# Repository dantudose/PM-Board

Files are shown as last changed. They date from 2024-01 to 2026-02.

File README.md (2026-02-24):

# PM-Board

## Embedded development board with ATmega324P

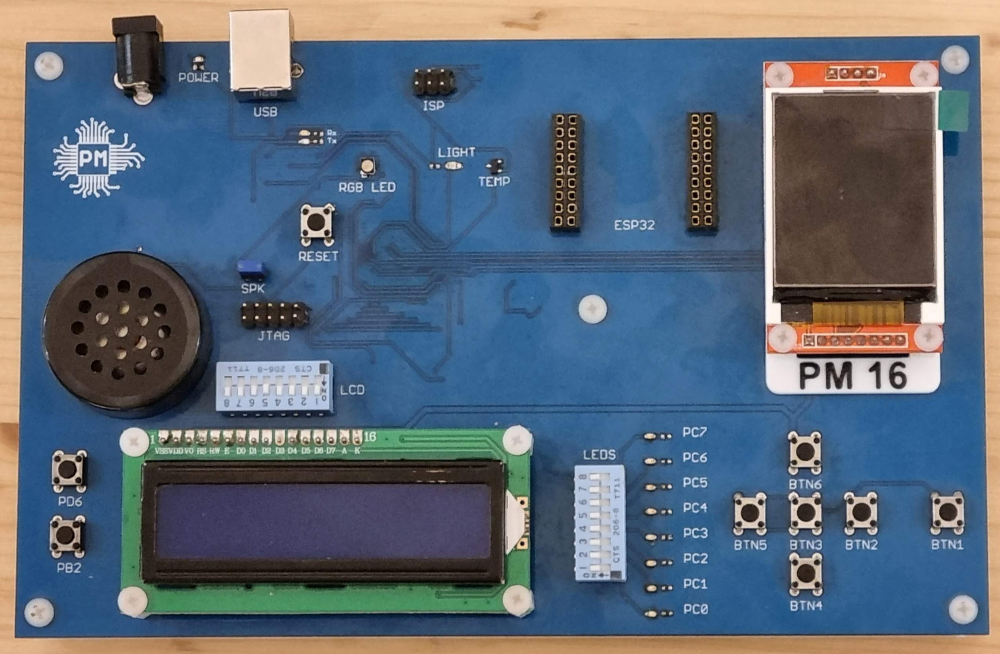
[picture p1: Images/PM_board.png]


This is a development board supporting the ATmega324P microcontroller. It is fully Arduino-compatible and it comes with the following features:
* LSM9DS0 9-axis inertial sensor (accelerometer, gyroscope and magnetometer)
* MPL3115 baro-altimeter sensor
* Ambient temperature and light sensors
* 128x160 ST7735 color LCD display with SD card reader 
* RGB LED
* 16x02 character LCD display
* GPIO LEDs and pushbuttons
* JTAG and ISP connectors
* USB programming and data interface

<div id="cover">
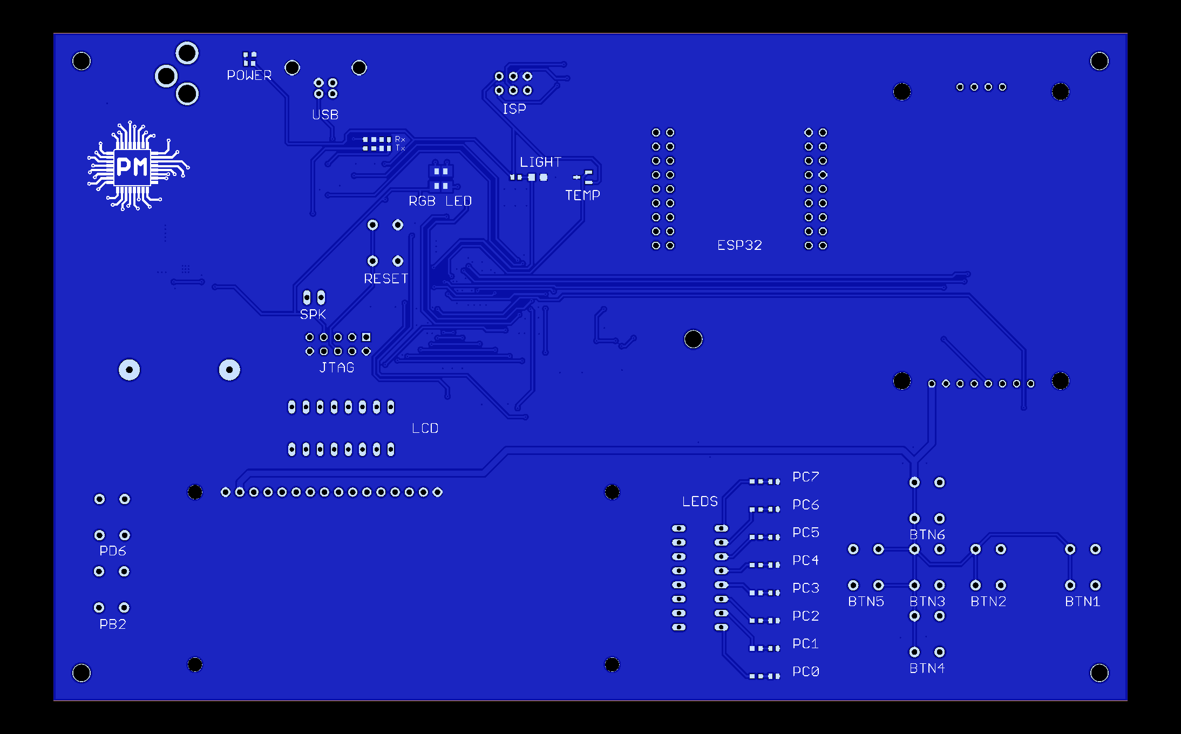
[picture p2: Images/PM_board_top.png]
  
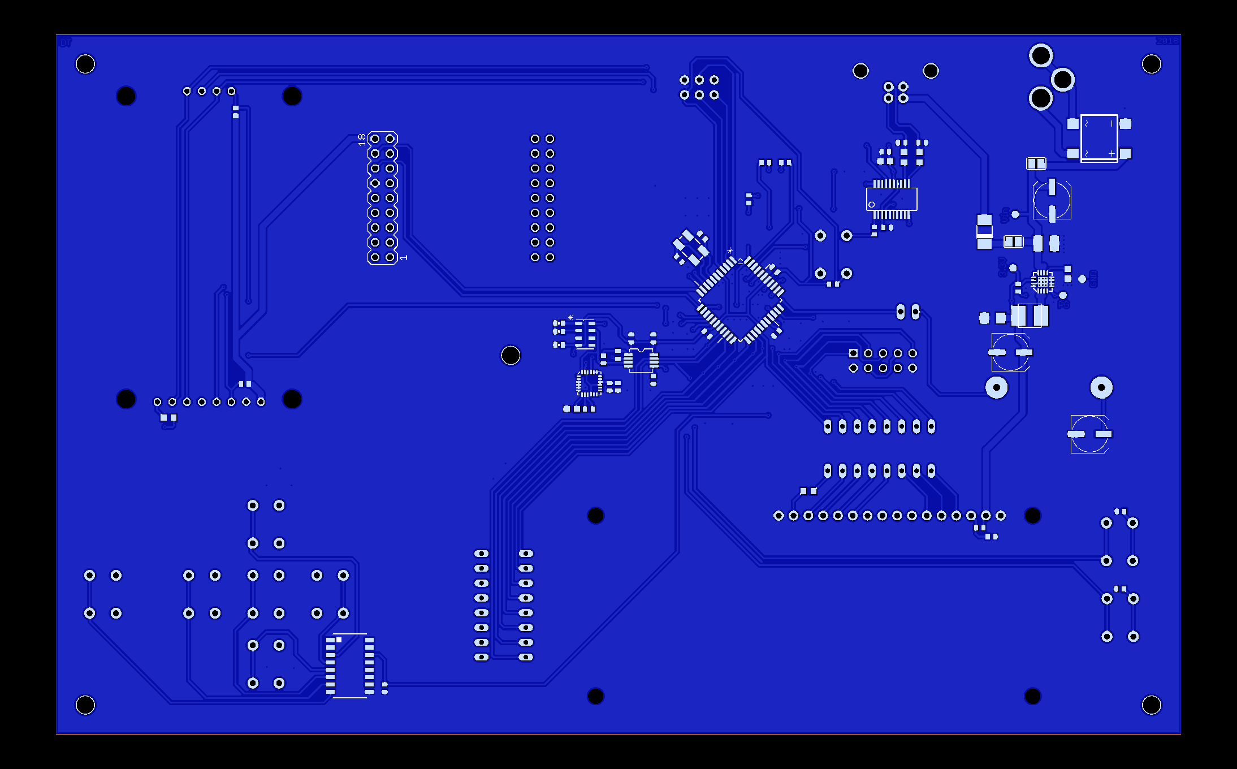
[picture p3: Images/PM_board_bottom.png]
   
</div>

## Repository Contents

* **/Code** - Test code for the board (PlatformIO)
* **/Hardware** - Eagle design files (.brd, .sch)
* **/Images** - Board images
* **/bin** - Binaries (board bootloader)

## Programming

### avr-gcc & Makefile

#### Bootloader
The board comes pre-loaded with a bootloader. If you need to re-write it, connect an AVR-ISP or JTAG to the corresponding port and burn the <a href="https://github.com/dantudose/PM-Board/tree/main/bin">bootloader</a> .hex file with _atmega324p_ as a target and the following fuse settings:

<table>
<thead>
  <tr>
    <th>Fuse</th>
    <th>Value</th>
  </tr>
</thead>
<tbody>
  <tr>
    <td>HIGH</td>
    <td>0xDA</td>
  </tr>
  <tr>
    <td>LOW</td>
    <td>0xD7</td>
  </tr>
  <tr>
    <td>EXT</td>
    <td>0XFD</td>
  </tr>
</tbody>
</table>

#### Writing a simple Hello World

Install avr-gcc on your machine. There are various tutorials on how to do this. Here are some examples, depending on your OS type:
* <a href="https://tinusaur.com/guides/avr-gcc-toolchain/">Windows</a>
* <a href="https://baremetalmicro.com/tutorial_avr_toolchain/03-Install-on-Ubuntu-Linux.html">Linux</a>
* <a href="https://wellys.com/posts/avr_c_macos/">Mac</a>

Copy this code into your favourite code editor and save the file as "hello.c":

```cpp
#include <avr/io.h>
#include <util/delay.h>
 
int main() {
	/* Setting PC0 as output */
	DDRC |= (1 << PC0);
 
	while(1) {
                /* Toggle pin state */
		PORTC ^= (1 << PC0);
 
                _delay_ms(500);
	}
 
	return 0;
}

```
To build and upload, you can use the following Makefile. Edit the port to correspond with your OS and serial port name:

```Makefile
# Linux
PORT ?= /dev/ttyUSB0
# Windows
# PORT ?= COM1
 
all: hello.hex
 
hello.hex: hello.elf
	avr-objcopy  -j .text -j .data -O ihex $^ $@
	avr-size hello.elf
 
hello.elf: hello.c
	avr-g++ -mmcu=atmega324p -DF_CPU=12000000 -Os -Wall -o $@ $^
 
upload: hello.hex
	avrdude -c urclock -P $(PORT) -b 57600 -p atmega324p -D -xnometadata -U flash:w:$<:a
 
clean:
	rm -rf hello.elf hello.hex
```

From your command line call _> make all_ (generates hello.hex) and then _> make upload_.

### Arduino

The board can be programmed using <a href="https://github.com/MCUdude/MightyCore">Mighty-Core</a>. 

Follow the "How to install" guide on their github page and use the following settings when burning the bootloader and uploading a sketch:

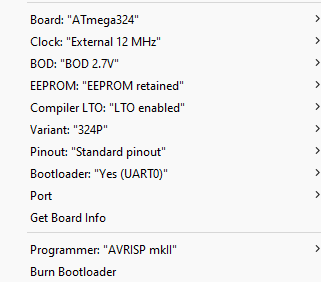
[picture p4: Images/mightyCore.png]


### PlatformIO (VSCode)

Use the /Code project as reference. 

## Board Pinout

#### LCD Displays

<table>
<thead>
  <tr>
    <th>Character LCD</th>
    <th>GPIO Pin</th>
    <th>Arduino Pin</th>
    <th></th>
    <th>Graphical LCD</th>
    <th>GPIO Pin</th>
    <th>Arduino Pin</th>
  </tr>
</thead>
<tbody>
  <tr>
    <td>RS</td>
    <td>PC0</td>
    <td>16</td>
    <td></td>
    <td>CS</td>
    <td>PB0</td>
    <td>0</td>
  </tr>
  <tr>
    <td>RW</td>
    <td>PC1</td>
    <td>17</td>
    <td></td>
    <td>RST</td>
    <td>PB1</td>
    <td>1</td>
  </tr>
  <tr>
    <td>EN</td>
    <td>PC2</td>
    <td>18</td>
    <td></td>
    <td>A0</td>
    <td>PB4</td>
    <td>4</td>
  </tr>
  <tr>
    <td>D4</td>
    <td>PC3</td>
    <td>19</td>
    <td></td>
    <td>SDA</td>
    <td>PB5</td>
    <td>5</td>
  </tr>
  <tr>
    <td>D5</td>
    <td>PC4</td>
    <td>20</td>
    <td></td>
    <td>SCK</td>
    <td>PB7</td>
    <td>7</td>
  </tr>
  <tr>
    <td>D6</td>
    <td>PC5</td>
    <td>21</td>
    <td></td>
    <td>Backlight</td>
    <td>PA7</td>
    <td>31</td>
  </tr>
  <tr>
    <td>D7</td>
    <td>PC6</td>
    <td>22</td>
    <td></td>
    <td></td>
    <td></td>
    <td></td>
  </tr>
  <tr>
    <td>Backlight</td>
    <td>PC7</td>
    <td>23</td>
    <td></td>
    <td></td>
    <td></td>
    <td></td>
  </tr>
</tbody>
</table>

#### I2C Sensors & Bus Addresses

<table style="float: left; width: 584.312px;">
<tbody>
<tr>
<td style="width: 76px;">&nbsp;<strong>I2C</strong></td>
<td style="width: 103px;"><strong>&nbsp;GPIO Pin</strong>&nbsp;</td>
<td style="width: 94px;"><strong>&nbsp;Arduino Pin</strong>&nbsp;</td>
<td style="width: 35px;">&nbsp;</td>
<td style="width: 98px;"><strong>&nbsp;Chip</strong>&nbsp;</td>
<td style="width: 162.312px;"><strong>&nbsp;Address</strong>&nbsp;</td>
</tr>
<tr>
<td style="width: 76px;">&nbsp;I2C Enable&nbsp;</td>
<td style="width: 103px;">&nbsp;PA6</td>
<td style="width: 94px;">&nbsp;30</td>
<td style="width: 35px;">&nbsp;</td>
<td style="width: 98px;">&nbsp;LSM9DS0&nbsp;</td>
<td style="width: 162.312px;">&nbsp;0x1D (XM) 0x6B (G)</td>
</tr>
<tr>
<td style="width: 76px;">&nbsp;SCL&nbsp;</td>
<td style="width: 103px;">&nbsp;PC0&nbsp;</td>
<td style="width: 94px;">&nbsp;16</td>
<td style="width: 35px;">&nbsp;</td>
<td style="width: 98px;">&nbsp;MPL3115A2&nbsp;</td>
<td style="width: 162.312px;">&nbsp;0x60&nbsp;</td>
</tr>
<tr>
<td style="width: 76px;">&nbsp;SDA&nbsp;</td>
<td style="width: 103px;">&nbsp;PC1&nbsp;</td>
<td style="width: 94px;">&nbsp;17&nbsp;</td>
<td style="width: 35px;">&nbsp;</td>
<td style="width: 98px;">&nbsp;</td>
<td style="width: 162.312px;">&nbsp;</td>
</tr>
</tbody>
</table>
<!-- DivTable.com -->

#### SD Card

<table style="float: left;">
<tbody>
<tr>
<td>&nbsp;<b> </b>&nbsp;</td>
<td>&nbsp;<b>GPIO Pin</b>&nbsp;</td>
<td>&nbsp;<b>Arduino Pin</b>&nbsp;</td>
</tr>
<tr>
<td>&nbsp;CS</td>
<td>&nbsp;PA2</td>
<td>&nbsp;26</td>
</tr>
<tr>
<td>&nbsp;MOSI&nbsp;</td>
<td>&nbsp;PB5&nbsp;</td>
<td>&nbsp;5&nbsp;</td>
</tr>
<tr>
<td>&nbsp;MISO&nbsp;</td>
<td>&nbsp;PB6&nbsp;</td>
<td>&nbsp;6&nbsp;</td>
</tr>
<tr>
<td>&nbsp;SCK&nbsp;</td>
<td>&nbsp;PB7&nbsp;</td>
<td>&nbsp;7&nbsp;</td>
</tr>
</tbody>
</table>
<!-- DivTable.com -->

#### RGB LED

<table class="tg">
<thead>
  <tr>
    <th class="tg-amwm"> </th>
    <th class="tg-amwm">GPIO Pin</th>
    <th class="tg-amwm">Arduino Pin</th>
  </tr>
</thead>
<tbody>
  <tr>
    <td class="tg-hmp3">Red</td>
    <td class="tg-hmp3">PD5</td>
    <td class="tg-hmp3">13</td>
  </tr>
  <tr>
    <td class="tg-0lax">Green</td>
    <td class="tg-0lax">PD7</td>
    <td class="tg-0lax">15</td>
  </tr>
  <tr>
    <td class="tg-hmp3">Blue</td>
    <td class="tg-hmp3">PB3</td>
    <td class="tg-hmp3">3</td>
  </tr>
</tbody>
</table>

### Miscellaneous

<table class="tg">
<thead>
  <tr>
    <th class="tg-0lax"></th>
    <th class="tg-amwm">GPIO Pin</th>
    <th class="tg-amwm">Arduino Pin</th>
  </tr>
</thead>
<tbody>
  <tr>
    <td class="tg-0lax">Temperature Sensor</td>
    <td class="tg-0lax">PA0</td>
    <td class="tg-0lax">A0</td>
  </tr>
  <tr>
    <td class="tg-0lax">Ambient Light Sensor</td>
    <td class="tg-0lax">PA1</td>
    <td class="tg-0lax">A1</td>
  </tr>
  <tr>
    <td class="tg-0lax">BUTTON 1 (PB2)</td>
    <td class="tg-0lax">PB2</td>
    <td class="tg-0lax">2</td>
  </tr>
  <tr>
    <td class="tg-0lax">BUTTON 2 (PD6)</td>
    <td class="tg-0lax">PD6</td>
    <td class="tg-0lax">14</td>
  </tr>
  <tr>
    <td class="tg-0lax">Buttons (BTN1 - 6)</td>
    <td class="tg-0lax">PA5</td>
    <td class="tg-0lax">A5</td>
  </tr>
  <tr>
    <td class="tg-0lax">Speaker</td>
    <td class="tg-0lax">PD4</td>
    <td class="tg-0lax">12</td>
  </tr>
</tbody>
</table>

## License Information

This product is _**open source**_! 

Please review the LICENSE file for license information. 

Distributed as-is; no warranty is given.

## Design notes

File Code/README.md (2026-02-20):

# PM-Board Test

PlatformIO project for validating the PM-board. The firmware brings up the board peripherals, reads sensors over I2C/ADC, and renders live values on the TFT display while driving status LEDs and the speaker.

## What the firmware does

- Runs an RGB LED self-test sequence on boot.
- Initializes the SD card interface and reports the card type over serial and the 16x2 LCD.
- Plays a short tone sequence on the speaker.
- Powers the I2C domain and brings up:
  - LSM9DS0 IMU (accel/gyro/mag)
  - MPL3115A2 barometer (altitude + temperature)
- Updates a 1.8" ST7735 TFT (Ucglib) with live readings and bar graphs.
- Reads analog channels for temperature, light, and a button ladder.
- Uses two digital buttons to toggle the RGB status LED colors.

## Board signals and pins

| Signal | Pin | Notes |
| --- | --- | --- |
| Speaker | 12 | Plays startup tune |
| GLCD backlight | 31 | TFT backlight control |
| ADC temp | A0 | Analog input |
| ADC light | A1 | Analog input |
| ADC buttons | A5 | Analog button ladder |
| I2C enable | 30 | Powers I2C domain |
| LCD RS | 16 | 16x2 LCD |
| LCD EN | 18 | 16x2 LCD |
| LCD RW | 17 | 16x2 LCD (held LOW) |
| LCD D4..D7 | 19..22 | 4-bit LCD bus |
| LCD backlight | 23 | 16x2 LCD |
| Button up | 14 | Active LOW |
| Button down | 2 | Active LOW |
| LED red | 13 | Active LOW |
| LED green | 15 | Active LOW |
| LED blue | 3 | Active LOW |
| SD chip select | 26 | Uses hardware SPI |
| TFT DC (A0) | 4 | Uses hardware SPI |
| TFT CS | 0 | Uses hardware SPI |
| TFT RESET | 1 | Uses hardware SPI |

I2C devices and addresses:

- LSM9DS0: 0x6B (gyro), 0x1D (xm), expected WHO_AM_I 0x49D4
- MPL3115A2: 0x60, expected WHO_AM_I 0xC4

## Build

```sh
platformio run -e ATmega324P
```

## Dependencies

Declared in `platformio.ini`:

- Ucglib
- SparkFun LSM9DS0 Arduino Library
- LiquidCrystal

## Configuration notes

- IMU output units: toggle `PRINT_CALCULATED` or `PRINT_RAW` in `src/main.cpp`.
- Display orientation is set to 180 degrees in `initDisplay()`.
- Barometer is configured in altimeter mode with oversample rate 128.

## Serial output

The firmware uses 115200 baud for boot logs and sensor presence checks.

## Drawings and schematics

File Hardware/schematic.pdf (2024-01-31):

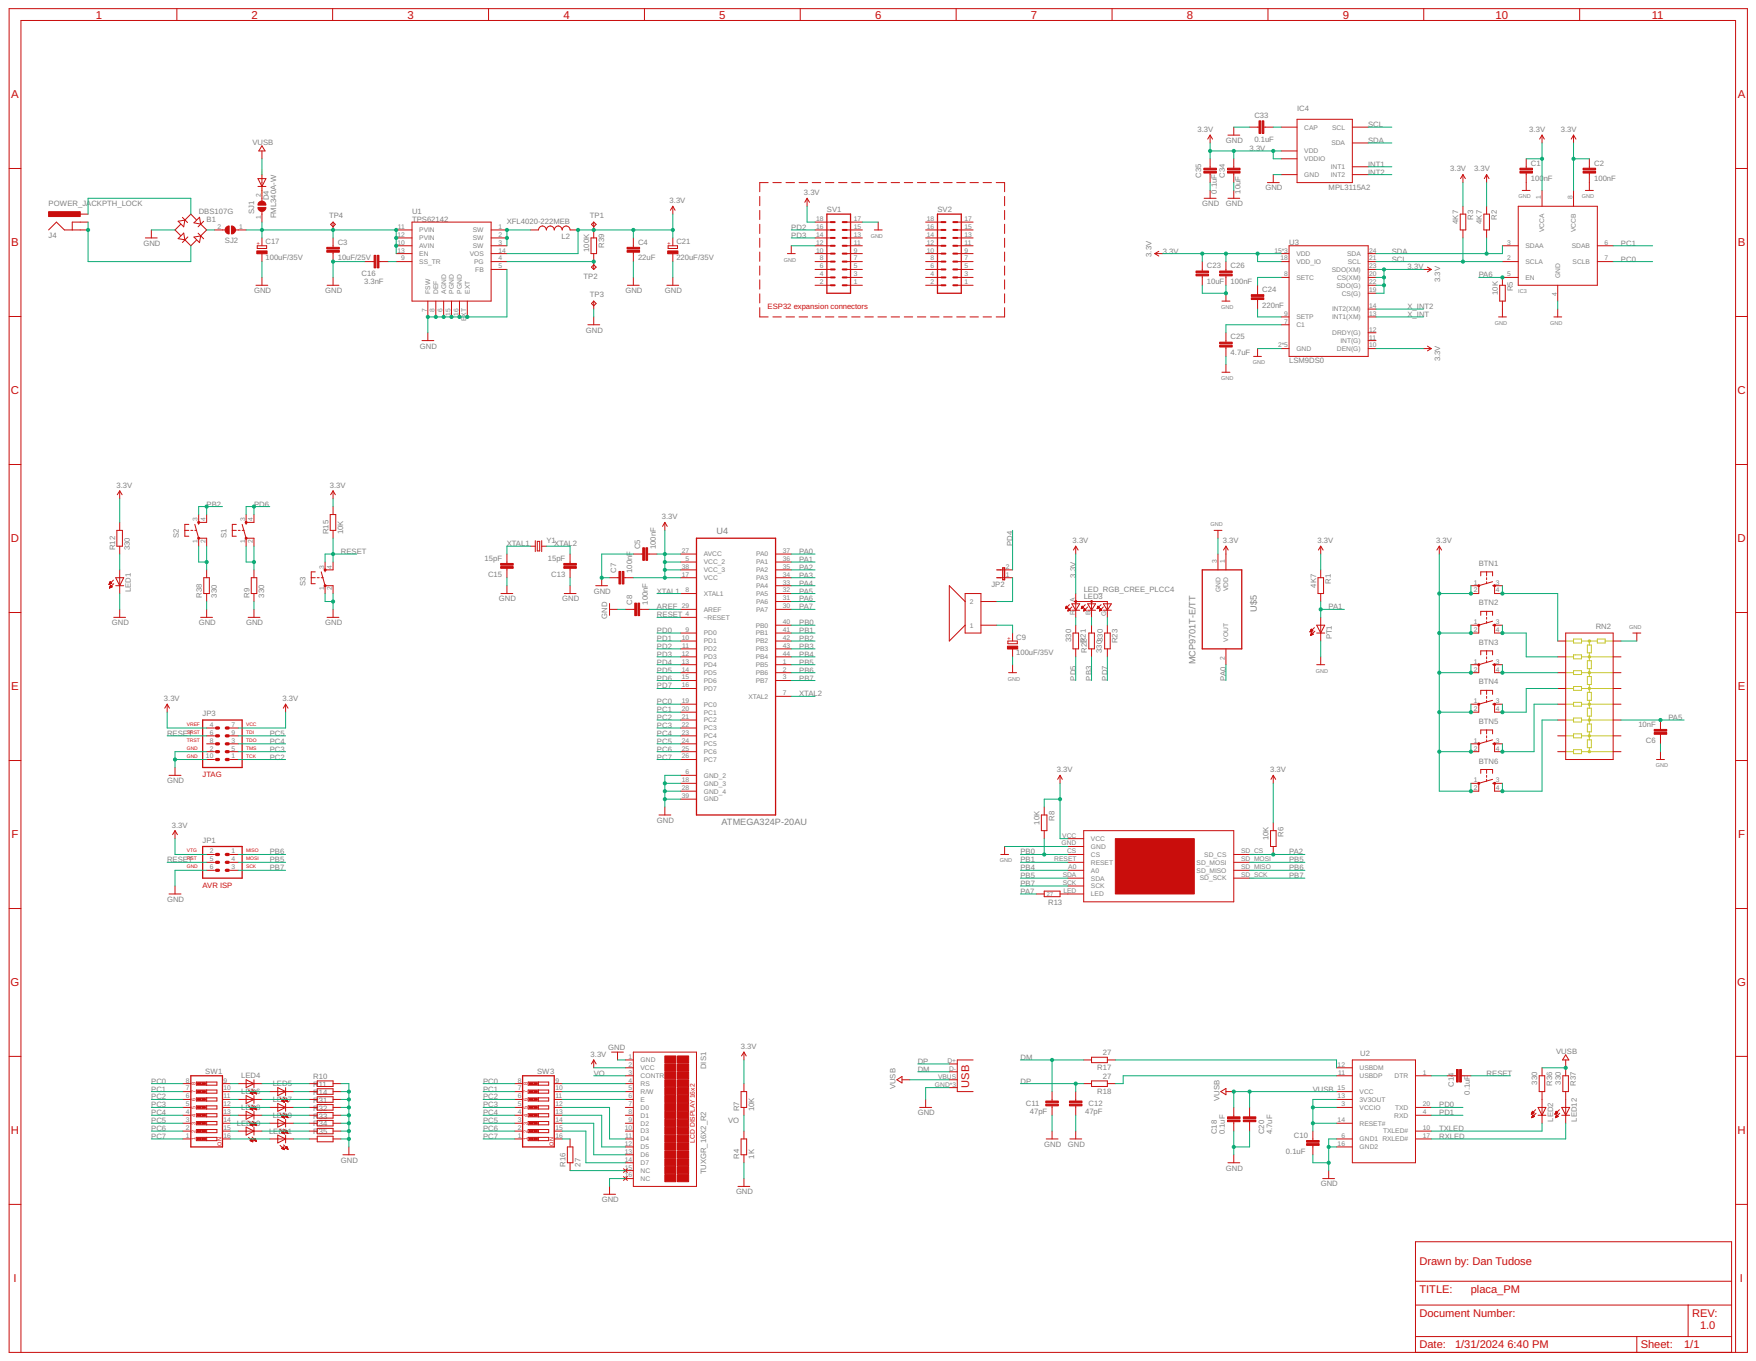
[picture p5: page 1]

Drawn by: Dan Tudose

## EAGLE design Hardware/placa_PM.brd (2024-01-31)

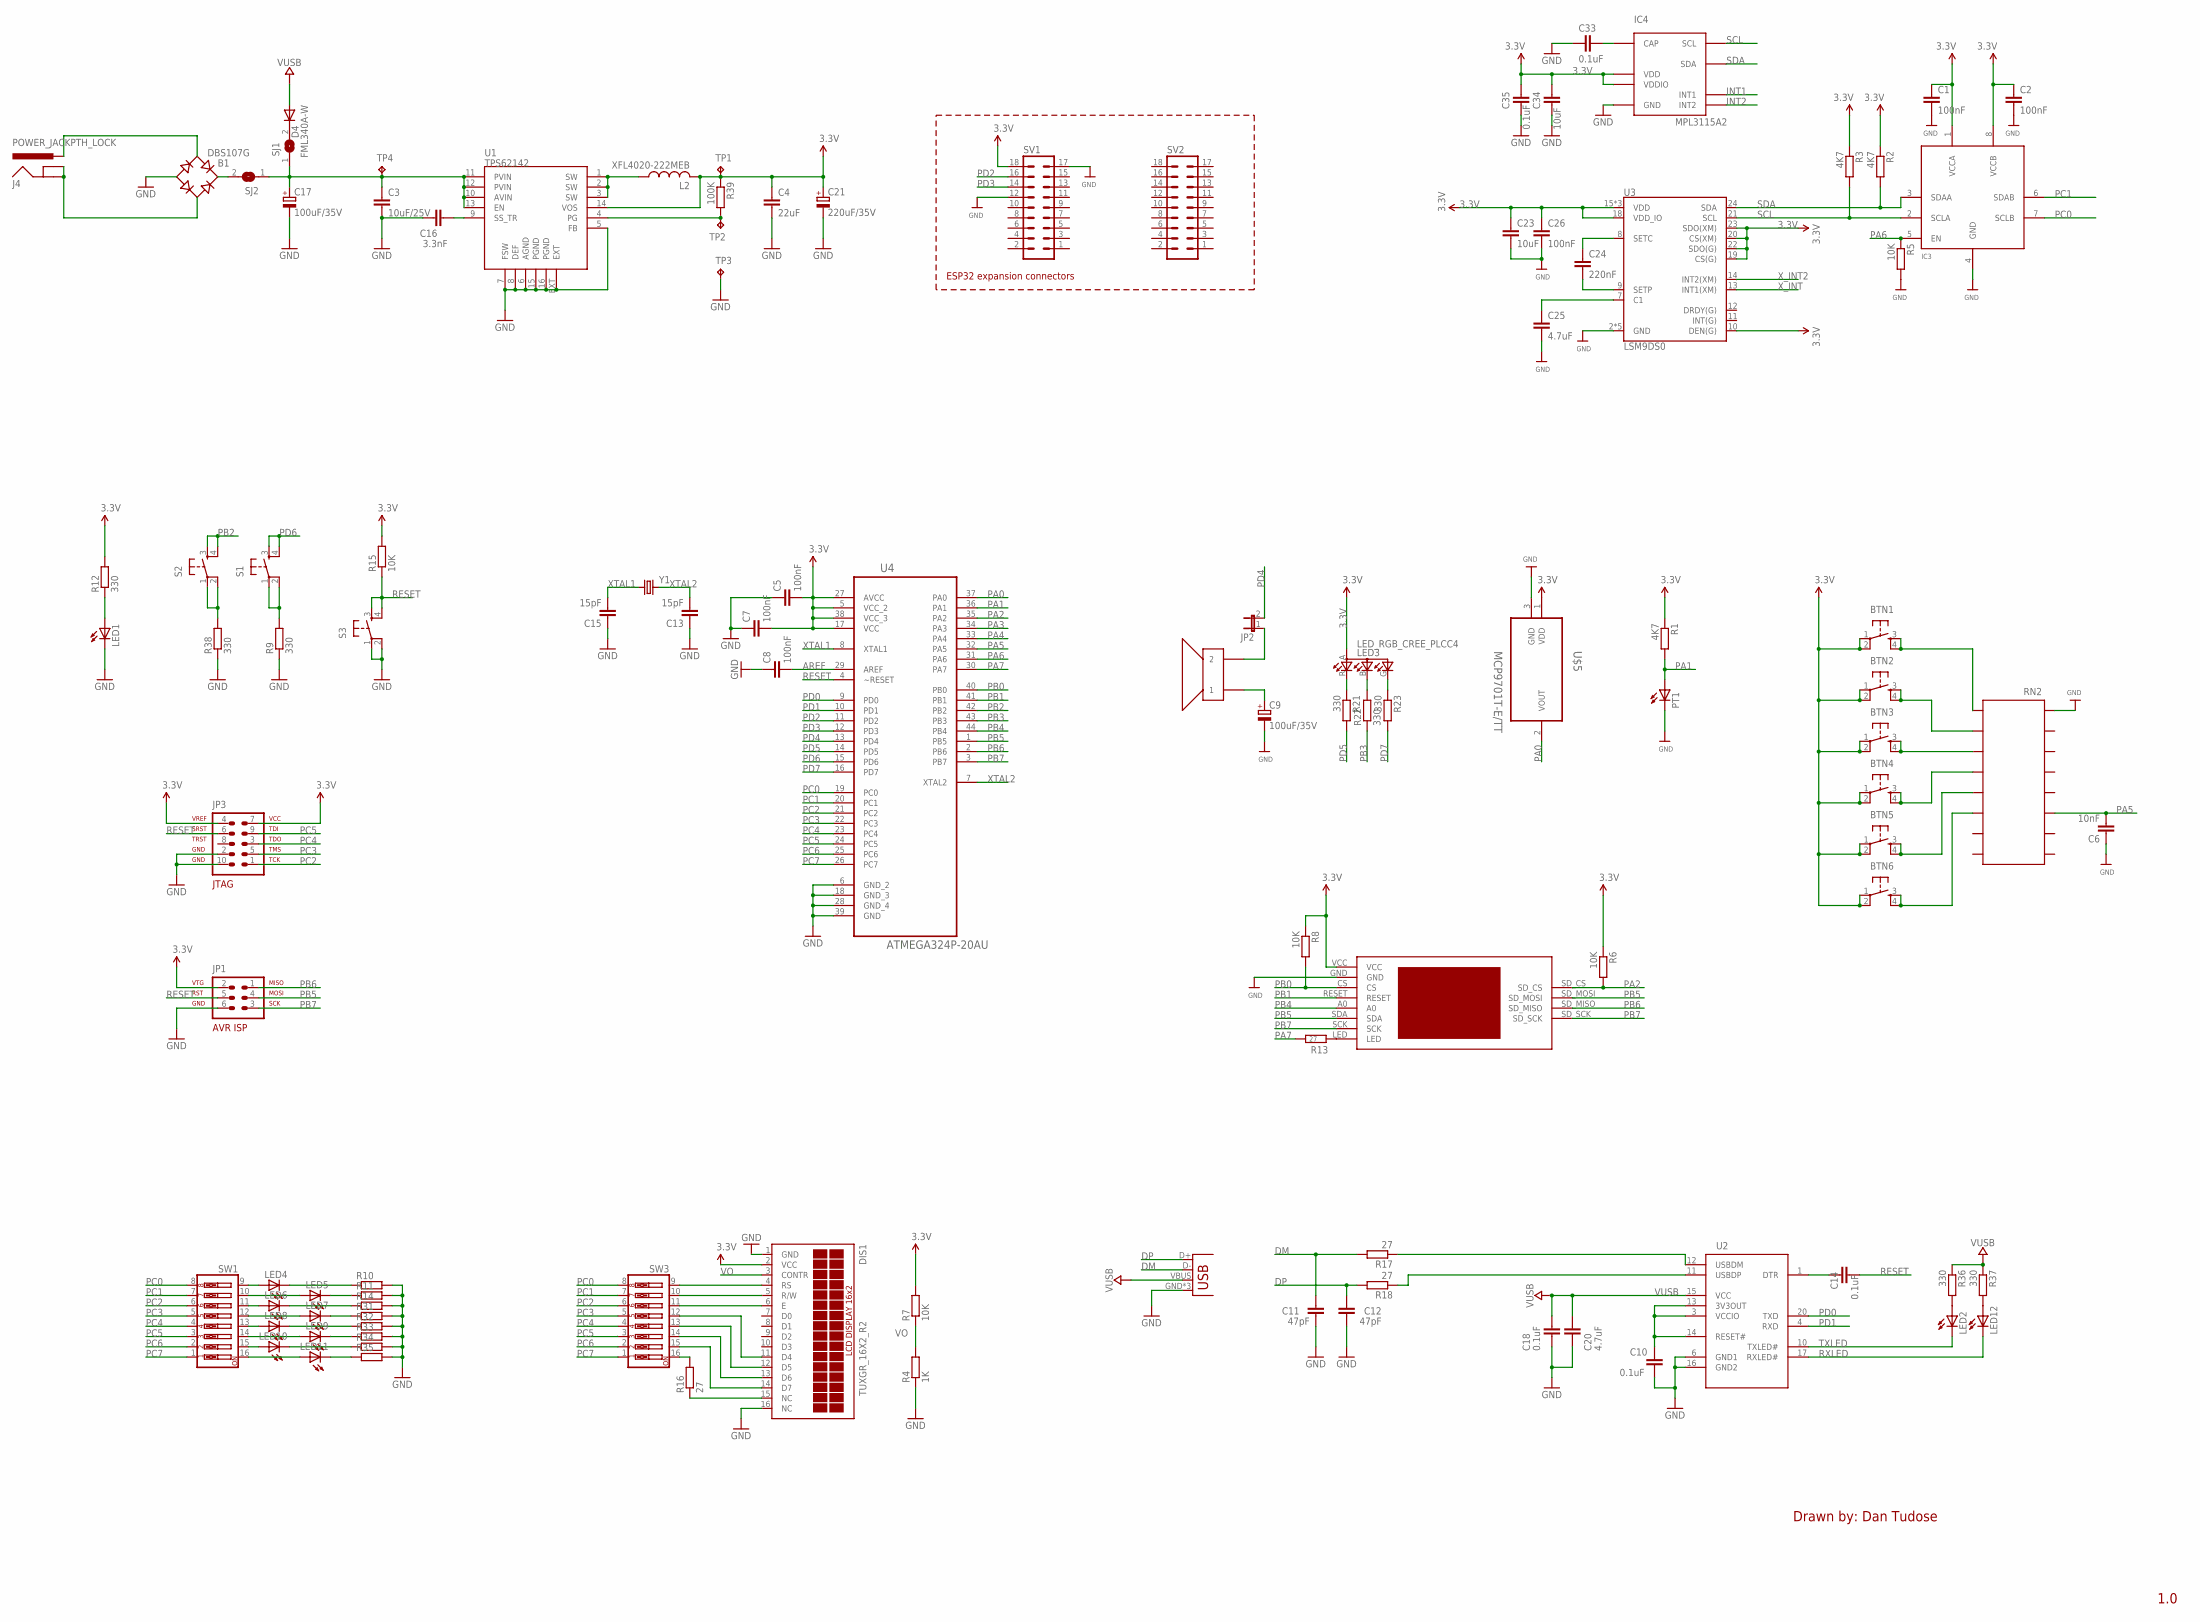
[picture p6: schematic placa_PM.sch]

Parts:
B1: DBS107G; DBS
BTN1, BTN2, BTN3, BTN4, BTN5, BTN6: TAC_SWITCHPTH; TACTILE-PTH
C1, C2, C5, C7, C8, C26: 100nF; C0402
C3: 10uF/25V; C1210
C4: 22uF; C1206
C6: 10nF; C0402
C9, C17: 100uF/35V; UD-6,3X7,7_NICHICON
C10, C14, C18: 0.1uF; C0402
C11, C12: 47pF; C0402
C13, C15: 15pF; C0402
C16: 3.3nF; C0603
C20, C25: 4.7uF; C0603
C21: 220uF/35V; UD-6,3X7,7_NICHICON
C23: 10uF; C0402
C24: 220nF; C0402
C33, C35: 0.1uF; 0402-CAP
C34: 10uF; 0402-CAP
D4: FML340A-W; DO-214AC
DIS1: TUXGR_16X2_R2
IC3: TCA9803VSS; VSSOP8
IC4: MPL3115A2; LGA8R125P0X4_500X300X120
J3: USBPTH; USB-B-PTH
J4: POWER_JACKPTH_LOCK; POWER_JACK_PTH_LOCK
JP1: AVR-ISP-6
JP2: JP1E; JP1
JP3: AVR-JTAG-10
L2: XFL4020-222MEB; XFL4020
LED1: LEDCHIPLED_0603; CHIPLED_0603
LED2, LED4, LED5, LED6, LED7, LED8, LED9, LED10, LED11, LED12: LEDCHIP-LED0603; CHIP-LED0603
LED3: LED_RGB_CREE_PLCC4; P-LCC-4-4
PT1: LEDSML0805; SML0805
R1, R2, R3: 4K7; R0402
R4: 1K; R0402
R5, R6, R7, R8, R15: 10K; R0402
R9, R12, R21, R22, R23, R36, R37, R38: 330; R0402
R10, R11, R14, R31, R32, R33, R34, R35: R-EU_R0402; R0402
R13, R16, R17, R18: 27; R0603
R39: 100K; R0402
RN2: 4816P-R2R; 4816P
S1, S2, S3: TAC_SWITCHPTH; TACTILE-PTH
SJ1, SJ2: SJ
SV1, SV2: MA09-2
SW1, SW3: SW_DIP-8; EDG-08
TP1, TP2, TP3, TP4: TPB1,27; B1,27
U1: TPS62142; QFN16-3X3MM_1:1_V03
U2: FT231XS; SSOP20
U3: LSM9DS0; LGA-24
U4: ATMEGA324P-20AU; QFP80P1200X1200X120-44N
U$5: MCP9701T-E/TT; SOT95P237X112-3N
U$6: CVS-3108; SPK
U$8: LCD128X160
Y1: CRYSTAL5X3; CRYSTAL-SMD-5X3

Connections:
3.3V: BTN1.1, BTN1.2, BTN2.1, BTN2.2, BTN3.1, BTN3.2, BTN4.1, BTN4.2, BTN5.1, BTN5.2, BTN6.1, BTN6.2, C1.1, C2.1, C4.1, C5.2, C7.2, C21.+, C23.1, C26.1, C34.2, C35.2, DIS1.2 (VCC), IC3.1 (VCCA), IC3.8 (VCCB), IC4.1 (VDD), IC4.4 (VDDIO), JP1.2, JP3.4, JP3.7, L2.P$2 (2), LED3.A (A2), R1.1, R2.1, R3.1, R6.1, R7.2, R8.1, R12.2, R15.2, R39.1, SV1.18, TP1.TP, U1.14 (VOS), U3.10 (DEN(G)), U3.15 (VDD), U3.16 (VDD), U3.17 (VDD), U3.18 (VDD_IO), U3.19 (CS(G)), U3.20 (CS(XM)), U3.22 (SDO(G)), U3.23 (SDO(XM)), U4.5 (VCC_2), U4.17 (VCC), U4.27 (AVCC), U4.38 (VCC_3), U$5.1 (VDD), U$8.VCC
AREF: C8.2, U4.29 (AREF)
DM: C11.2, J3.D-, R17.2
DP: C12.2, J3.D+, R18.2
GND: B1.-, C1.2, C2.2, C3.2, C4.2, C5.1, C6.1, C7.1, C8.1, C9.-, C10.2, C11.1, C12.1, C13.1, C15.1, C16.1, C17.-, C18.2, C20.2, C21.-, C23.2, C25.2, C26.2, C33.1, C34.1, C35.1, DIS1.1 (GND), DIS1.16 (NC), IC3.4 (GND), IC4.3 (GND), J3.GND, J3.P$1 (GND), J3.P$2 (GND), JP1.6, JP3.2, JP3.10, LED1.C, PT1.C, R4.1, R5.2, R9.1, R10.2, R11.2, R14.2, R31.2, R32.2, R33.2, R34.2, R35.2, R38.1, RN2.9, S3.1, S3.2, SV1.12, SV1.17, TP3.TP, U1.5 (FB), U1.6 (AGND), U1.7 (FSW), U1.8 (DEF), U1.15 (PGND), U1.16 (PGND), U1.EXT, U2.6 (GND1), U2.16 (GND2), U3.2 (GND), U3.3 (GND), U3.4 (GND), U3.5 (GND), U3.6 (GND), U4.6 (GND_2), U4.18 (GND_3), U4.28 (GND_4), U4.39 (GND), U$5.3 (GND), U$8.GND
INT1: IC4.6 (INT1)
INT2: IC4.5 (INT2)
unnamed: BTN1.3, BTN1.4, RN2.8
unnamed: LED1.A, R12.1
unnamed: JP2.1, U$6.P$2 (2)
unnamed: BTN2.3, BTN2.4, RN2.7
unnamed: DIS1.4 (RS), SW3.9
unnamed: C9.+, U$6.P$1 (1)
unnamed: DIS1.5 (R/W), SW3.10
unnamed: DIS1.15 (NC), R16.1
unnamed: R38.2, S2.1, S2.2
unnamed: D4.C, SJ1.2
unnamed: B1.AC1, J4.PWR
unnamed: B1.AC2, J4.GND, J4.GNDBREAK
unnamed: C3.1, C17.+, SJ1.1, SJ2.1, TP4.TP, U1.10 (AVIN), U1.11 (PVIN), U1.12 (PVIN), U1.13 (EN)
unnamed: BTN3.3, BTN3.4, RN2.6
unnamed: BTN4.3, BTN4.4, RN2.5
unnamed: DIS1.6 (E), SW3.11
unnamed: R9.2, S1.1, S1.2
unnamed: B1.+, SJ2.2
unnamed: BTN5.3, BTN5.4, RN2.4
unnamed: BTN6.3, BTN6.4, RN2.3
unnamed: R13.2, U$8.LED
unnamed: LED3.R (CRED), R21.1
unnamed: LED3.B (CBLUE), R22.2
unnamed: C14.1, U2.1 (DTR)
unnamed: C33.2, IC4.2 (CAP)
unnamed: LED3.G (CGREEN), R23.1
unnamed: C24.1, U3.8 (SETC)
unnamed: C24.2, U3.9 (SETP)
unnamed: C25.1, U3.7 (C1)
unnamed: DIS1.11 (D4), SW3.12
unnamed: DIS1.12 (D5), SW3.13
unnamed: C16.2, U1.9 (SS_TR)
unnamed: DIS1.13 (D6), SW3.14
unnamed: DIS1.14 (D7), SW3.15
unnamed: R16.2, SW3.16
unnamed: LED4.A, SW1.9
unnamed: LED6.A, SW1.11
unnamed: LED8.A, SW1.13
unnamed: LED10.A, SW1.15
unnamed: LED11.A, SW1.16
unnamed: LED9.A, SW1.14
unnamed: LED7.A, SW1.12
unnamed: LED5.A, SW1.10
unnamed: LED4.C, R10.1
unnamed: LED5.C, R11.1
unnamed: LED6.C, R14.1
unnamed: LED7.C, R31.1
unnamed: LED8.C, R32.1
unnamed: LED9.C, R33.1
unnamed: LED10.C, R34.1
unnamed: LED11.C, R35.1
unnamed: C10.1, U2.3 (VCCIO), U2.13 (3V3OUT), U2.14 (RESET#)
unnamed: R17.1, U2.12 (USBDM)
unnamed: R18.1, U2.11 (USBDP)
unnamed: LED2.A, R36.2
unnamed: LED12.A, R37.2
unnamed: L2.P$1 (1), U1.1 (SW), U1.2 (SW), U1.3 (SW)
unnamed: R39.2, TP2.TP, U1.4 (PG)
PA0: U4.37 (PA0), U$5.2 (VOUT)
PA1: PT1.A, R1.2, U4.36 (PA1)
PA2: R6.2, U4.35 (PA2), U$8.SD_CS
PA3: U4.34 (PA3)
PA4: U4.33 (PA4)
PA5: C6.2, RN2.14, U4.32 (PA5)
PA6: IC3.5 (EN), R5.1, U4.31 (PA6)
PA7: R13.1, U4.30 (PA7)
PB0: R8.2, U4.40 (PB0), U$8.CS
PB1: U4.41 (PB1), U$8.RESET
PB2: S2.3, S2.4, U4.42 (PB2)
PB3: R22.1, U4.43 (PB3)
PB4: U4.44 (PB4), U$8.A0
PB5: JP1.4, U4.1 (PB5), U$8.SDA, U$8.SD_MOSI
PB6: JP1.1, U4.2 (PB6), U$8.SD_MISO
PB7: JP1.3, U4.3 (PB7), U$8.SCK, U$8.SD_SCK
PC0: IC3.7 (SCLB), SW1.8, SW3.8, U4.19 (PC0)
PC1: IC3.6 (SDAB), SW1.7, SW3.7, U4.20 (PC1)
PC2: JP3.1, SW1.6, SW3.6, U4.21 (PC2)
PC3: JP3.5, SW1.5, SW3.5, U4.22 (PC3)
PC4: JP3.3, SW1.4, SW3.4, U4.23 (PC4)
PC5: JP3.9, SW1.3, SW3.3, U4.24 (PC5)
PC6: SW1.2, SW3.2, U4.25 (PC6)
PC7: SW1.1, SW3.1, U4.26 (PC7)
PD0: U2.20 (TXD), U4.9 (PD0)
PD1: U2.4 (RXD), U4.10 (PD1)
PD2: SV1.16, U4.11 (PD2)
PD3: SV1.14, U4.12 (PD3)
PD4: JP2.2, U4.13 (PD4)
PD5: R21.2, U4.14 (PD5)
PD6: S1.3, S1.4, U4.15 (PD6)
PD7: R23.2, U4.16 (PD7)
RESET: C14.2, JP1.5, JP3.6, R15.1, S3.3, S3.4, U4.4 (~RESET)
RXLED: LED12.C, U2.17 (RXLED#)
SCL: IC3.2 (SCLA), IC4.8 (SCL), R3.2, U3.21 (SCL)
SDA: IC3.3 (SDAA), IC4.7 (SDA), R2.2, U3.24 (SDA)
TXLED: LED2.C, U2.10 (TXLED#)
VO: DIS1.3 (CONTR), R4.2, R7.1
VUSB: C18.1, C20.1, D4.A, J3.VBUS, R36.1, R37.1, U2.15 (VCC)
XTAL1: C15.2, U4.8 (XTAL1), Y1.1
XTAL2: C13.2, U4.7 (XTAL2), Y1.3 (2)
X_INT: U3.13 (INT1(XM))
X_INT2: U3.14 (INT2(XM))

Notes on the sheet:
ESP32 expansion connectors
Drawn by: Dan Tudose
1.0

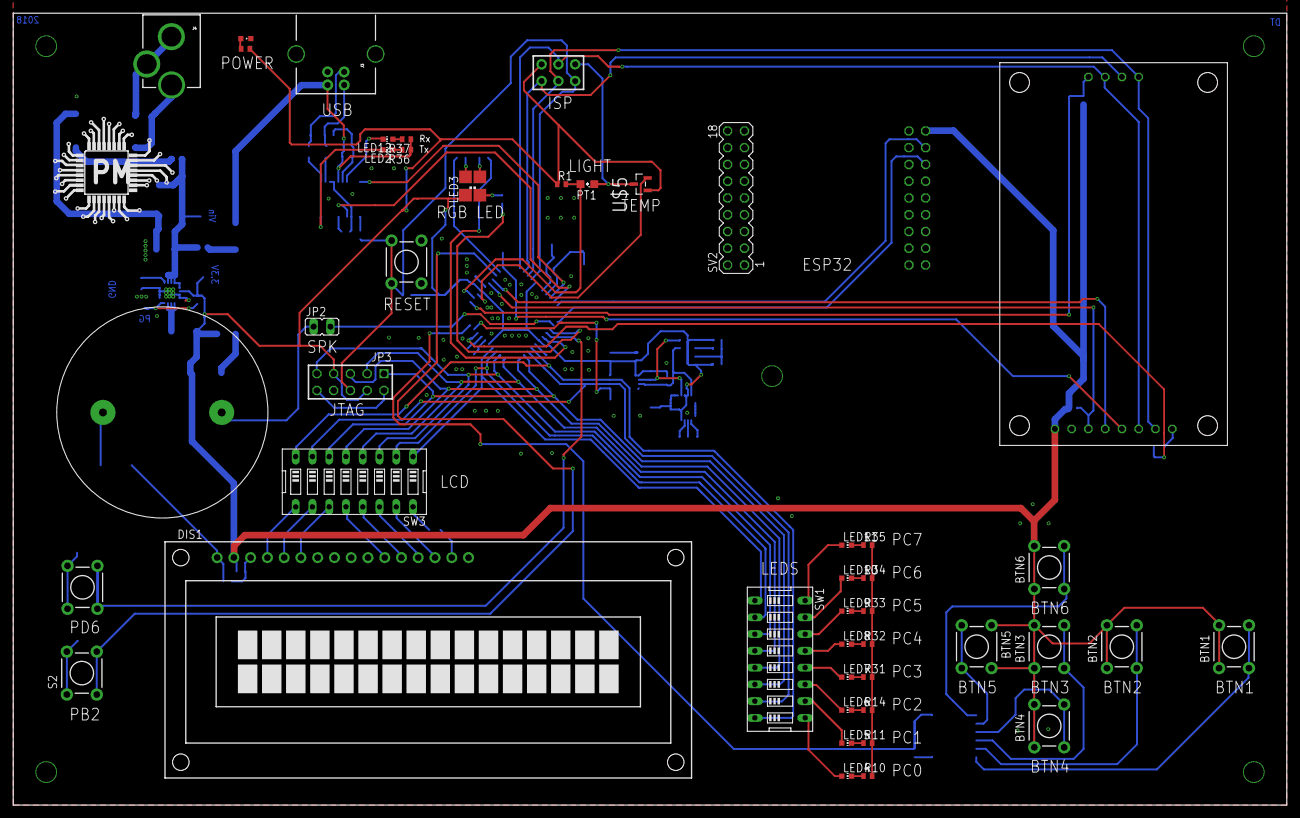
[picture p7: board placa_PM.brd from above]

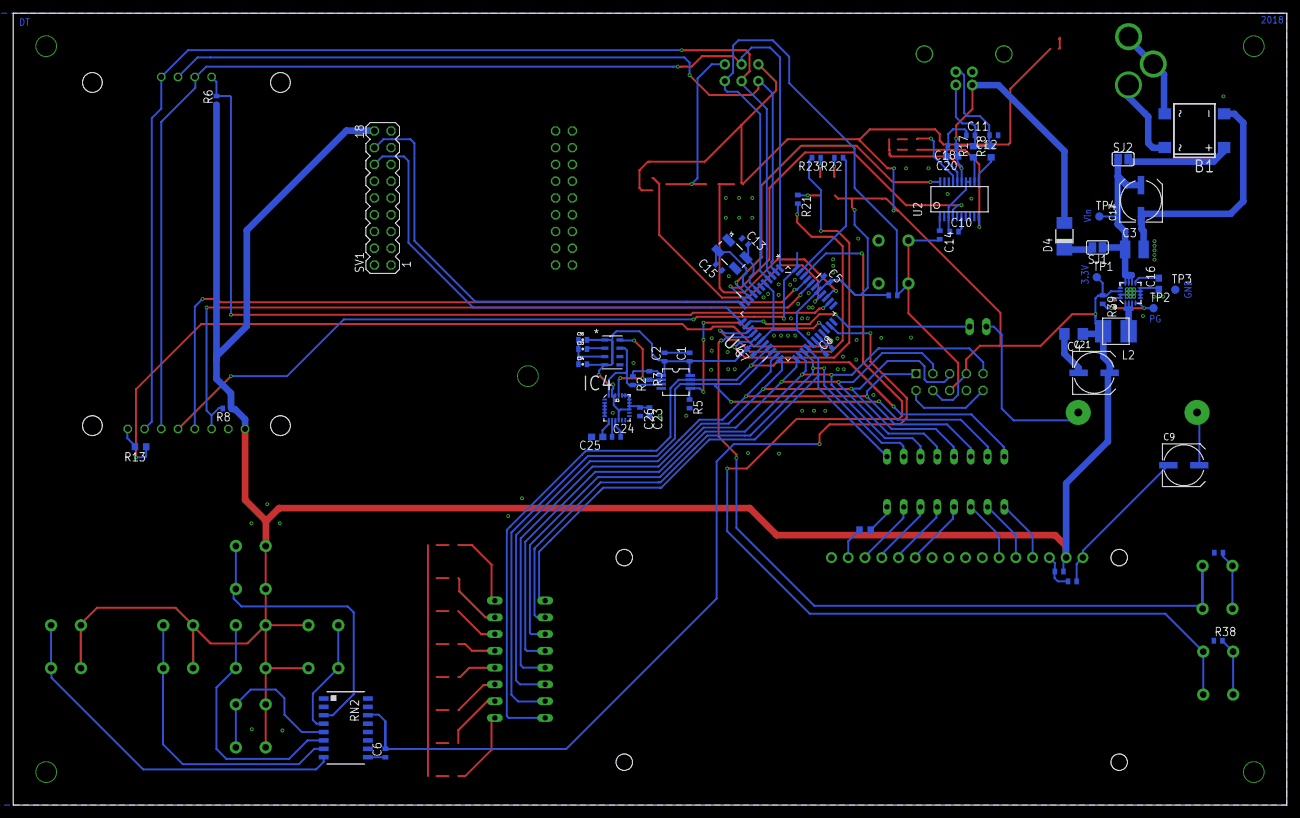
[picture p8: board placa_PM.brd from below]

Board: 2 copper layers, 193.0 x 120.0 mm, 109 parts (63 on the bottom side), 102 nets.

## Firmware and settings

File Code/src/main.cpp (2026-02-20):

#include <Arduino.h>
#include <SD.h>
#include <SPI.h>
#include <Wire.h>

#include <LiquidCrystal.h>
#include <SFE_LSM9DS0.h>

#include "Ucglib.h"
#include "pitches.h"

// Board pin map and device configuration.
namespace Pins {
constexpr uint8_t kSpeaker = 12;
constexpr uint8_t kGlcdBacklight = 31;
constexpr uint8_t kAdcTemp = A0;
constexpr uint8_t kAdcLight = A1;
constexpr uint8_t kAdcButtons = A5;
constexpr uint8_t kI2cEnable = 30;
constexpr uint8_t kLcdRs = 16;
constexpr uint8_t kLcdEn = 18;
constexpr uint8_t kLcdRw = 17;
constexpr uint8_t kLcdD4 = 19;
constexpr uint8_t kLcdD5 = 20;
constexpr uint8_t kLcdD6 = 21;
constexpr uint8_t kLcdD7 = 22;
constexpr uint8_t kLcdBacklight = 23;
constexpr uint8_t kButtonUp = 14;
constexpr uint8_t kButtonDown = 2;
constexpr uint8_t kLedRed = 13;
constexpr uint8_t kLedGreen = 15;
constexpr uint8_t kLedBlue = 3;
constexpr uint8_t kSdChipSelect = 26;
constexpr uint8_t kTftDc = 4;    // A0
constexpr uint8_t kTftCs = 0;
constexpr uint8_t kTftReset = 1;
}  // namespace Pins

namespace ImuConfig {
constexpr uint8_t kXmAddr = 0x1D;
constexpr uint8_t kGAddr = 0x6B;
constexpr uint16_t kWhoAmIExpected = 0x49D4;
}  // namespace ImuConfig

namespace BaroConfig {
constexpr uint8_t kAddress = 0x60;
constexpr uint8_t kRegStatus = 0x00;
constexpr uint8_t kRegOutPMsb = 0x01;
constexpr uint8_t kRegOutTMsb = 0x04;
constexpr uint8_t kRegWhoAmI = 0x0C;
constexpr uint8_t kRegPtDataCfg = 0x13;
constexpr uint8_t kRegCtrl1 = 0x26;
constexpr uint8_t kWhoAmIExpected = 196;
constexpr float kInvalidReading = -999.0f;
}  // namespace BaroConfig

constexpr uint16_t kAdcMax = 1024;
constexpr uint8_t kDisplayWidth = 128;

// Global devices.
LiquidCrystal lcd(
    Pins::kLcdRs,
    Pins::kLcdEn,
    Pins::kLcdD4,
    Pins::kLcdD5,
    Pins::kLcdD6,
    Pins::kLcdD7);
Ucglib_ST7735_18x128x160_HWSPI ucg(Pins::kTftDc, Pins::kTftCs, Pins::kTftReset);
LSM9DS0 imu(MODE_I2C, ImuConfig::kGAddr, ImuConfig::kXmAddr);
Sd2Card sdCard;

struct SensorReadings {
  int adcTemp = 0;
  int adcLight = 0;
  int adcButtons = 0;
  float baroAltitude = BaroConfig::kInvalidReading;
  float baroTemp = BaroConfig::kInvalidReading;
  float accelX = 0.0f;
  float accelY = 0.0f;
  float accelZ = 0.0f;
  float gyroX = 0.0f;
  float gyroY = 0.0f;
  float gyroZ = 0.0f;
  float magX = 0.0f;
  float magY = 0.0f;
  float magZ = 0.0f;
};

SensorReadings readings;
bool imuOnline = false;
bool baroOnline = false;

// Notes in the melody.
const uint16_t kMelody[] = {
    NOTE_C4, NOTE_G3, NOTE_G3, NOTE_A3, NOTE_G3, 0, NOTE_B3, NOTE_C4};
// Note durations: 4 = quarter note, 8 = eighth note, etc.
const uint8_t kNoteDurations[] = {4, 8, 8, 4, 4, 4, 4, 4};
constexpr size_t kMelodyLength = sizeof(kMelody) / sizeof(kMelody[0]);

// Build-time option for IMU output units.
#define PRINT_CALCULATED
// #define PRINT_RAW

// Forward declarations.
static void initPins();
static void initPortC();
static void setI2cPower(bool on);
static void setGlcdBacklight(bool on);
static void setStatusLed(bool redOn, bool greenOn, bool blueOn);
static void runLedSelfTest();
static void playTune();
static bool initSdCard();
static bool initImu();
static bool initBarometer();
static void initDisplay();
static void drawStaticLabels();
static void readAdc(SensorReadings &out);
static void readImu(SensorReadings &out);
static void readBarometer(SensorReadings &out);
static float readAltitudeMeters();
static float readTemperatureC();
static bool waitForBaroStatus(uint8_t mask);
static void setModeAltimeter();
static void setOversampleRate(uint8_t sampleRate);
static void toggleOneShot();
static void enableEventFlags();
static uint8_t i2cRead(uint8_t regAddr);
static void i2cWrite(uint8_t regAddr, uint8_t value);
static void updateDisplay(const SensorReadings &data);
static void setTextColor(bool ok);
static uint8_t clampBarLength(float length);
static void drawBar(uint8_t y, float length);
static void drawValueRow(float value,
                         uint8_t width,
                         uint8_t precision,
                         uint8_t valueX,
                         uint8_t valueY,
                         uint8_t lineY,
                         float barLength,
                         bool okColor);
static void updateStatusLeds();

void setup() {
  Serial.begin(115200);

  initPins();
  runLedSelfTest();

  setI2cPower(false);
  initPortC();

  lcd.begin(16, 2);
  initSdCard();

  playTune();

  setI2cPower(true);
  Wire.begin();

  imuOnline = initImu();
  baroOnline = initBarometer();

  initDisplay();
  drawStaticLabels();
}

void loop() {
  readAdc(readings);
  readBarometer(readings);
  readImu(readings);

  updateDisplay(readings);
  updateStatusLeds();
}

static void initPins() {
  pinMode(Pins::kButtonUp, INPUT_PULLUP);
  pinMode(Pins::kButtonDown, INPUT_PULLUP);

  pinMode(Pins::kLedRed, OUTPUT);
  pinMode(Pins::kLedGreen, OUTPUT);
  pinMode(Pins::kLedBlue, OUTPUT);

  pinMode(Pins::kSpeaker, OUTPUT);
  pinMode(Pins::kI2cEnable, OUTPUT);
  pinMode(Pins::kGlcdBacklight, OUTPUT);

  pinMode(Pins::kLcdRw, OUTPUT);
  digitalWrite(Pins::kLcdRw, LOW);
  pinMode(Pins::kLcdBacklight, OUTPUT);
  digitalWrite(Pins::kLcdBacklight, HIGH);
}

static void initPortC() {
  // Board-specific: drive Port C lines to a known state.
  DDRC = 0xFF;
  PORTC = 0xFF;
  delay(1000);
  PORTC = 0x00;
}

static void setI2cPower(bool on) {
  digitalWrite(Pins::kI2cEnable, on ? HIGH : LOW);
}

static void setGlcdBacklight(bool on) {
  digitalWrite(Pins::kGlcdBacklight, on ? HIGH : LOW);
}

static void setStatusLed(bool redOn, bool greenOn, bool blueOn) {
  // LEDs are active-low on this board.
  digitalWrite(Pins::kLedRed, redOn ? LOW : HIGH);
  digitalWrite(Pins::kLedGreen, greenOn ? LOW : HIGH);
  digitalWrite(Pins::kLedBlue, blueOn ? LOW : HIGH);
}

static void runLedSelfTest() {
  setStatusLed(false, false, false);
  delay(300);
  setStatusLed(true, false, false);
  delay(300);
  setStatusLed(false, true, false);
  delay(300);
  setStatusLed(false, false, true);
  delay(300);
  setStatusLed(false, false, false);
  delay(300);
}

static void playTune() {
  for (size_t i = 0; i < kMelodyLength; ++i) {
    int noteDuration = 1000 / kNoteDurations[i];
    tone(Pins::kSpeaker, kMelody[i], noteDuration);

    int pauseBetweenNotes = static_cast<int>(noteDuration * 1.30f);
    delay(pauseBetweenNotes);

    noTone(Pins::kSpeaker);
  }
}

static bool initSdCard() {
  if (!sdCard.init(SPI_HALF_SPEED, Pins::kSdChipSelect)) {
    Serial.println("SD init failed");
    Serial.println("- Is a card inserted?");
    Serial.println("- Is the wiring correct?");
    Serial.println("- Is chip select correct?");
    lcd.print("SD Init Fail");
    return false;
  }

  Serial.println("SD card initialized");
  Serial.print("Card type: ");
  switch (sdCard.type()) {
    case SD_CARD_TYPE_SD1:
      Serial.println("SD1");
      break;
    case SD_CARD_TYPE_SD2:
      Serial.println("SD2");
      break;
    case SD_CARD_TYPE_SDHC:
      Serial.println("SDHC");
      break;
    default:
      Serial.println("Unknown");
      break;
  }

  lcd.print("SD Card Found");
  lcd.setCursor(0, 1);
  lcd.print("FAT");
  delay(500);
  return true;
}

static bool initImu() {
  uint16_t status = imu.begin();
  Serial.print("LSM9DS0 WHO_AM_I returned: 0x");
  Serial.println(status, HEX);
  Serial.println("Expected: 0x49D4");
  return status == ImuConfig::kWhoAmIExpected;
}

static bool initBarometer() {
  if (i2cRead(BaroConfig::kRegWhoAmI) != BaroConfig::kWhoAmIExpected) {
    Serial.println("MPL3115A2 not detected");
    readings.baroAltitude = BaroConfig::kInvalidReading;
    readings.baroTemp = BaroConfig::kInvalidReading;
    return false;
  }

  Serial.println("MPL3115A2 online");

  setModeAltimeter();
  setOversampleRate(7);  // 128 samples
  enableEventFlags();
  return true;
}

static void initDisplay() {
  setGlcdBacklight(true);
  ucg.begin(UCG_FONT_MODE_SOLID);
  ucg.clearScreen();
  ucg.setRotate180();
  ucg.setFont(ucg_font_courR08_mr);
  ucg.setColor(0, 255, 255, 255);  // White text for static labels.
  ucg.setColor(1, 0, 0, 0);        // Black background.
}

static void drawStaticLabels() {
  ucg.setPrintPos(0, 8);
  ucg.print("Temp:");
  ucg.setPrintPos(0, 18);
  ucg.print("Light:");
  ucg.setPrintPos(0, 28);
  ucg.print("Buttons:");
  ucg.setPrintPos(0, 38);
  ucg.print("Baro Altitude:");
  ucg.setPrintPos(0, 48);
  ucg.print("Baro Temp:");
  ucg.setPrintPos(0, 58);
  ucg.print("Accel. X:");
  ucg.setPrintPos(0, 68);
  ucg.print("Accel. Y:");
  ucg.setPrintPos(0, 78);
  ucg.print("Accel. Z:");
  ucg.setPrintPos(0, 88);
  ucg.print("Gyro X:");
  ucg.setPrintPos(0, 98);
  ucg.print("Gyro Y:");
  ucg.setPrintPos(0, 108);
  ucg.print("Gyro Z:");
  ucg.setPrintPos(0, 118);
  ucg.print("Mag X:");
  ucg.setPrintPos(0, 128);
  ucg.print("Mag Y:");
  ucg.setPrintPos(0, 138);
  ucg.print("Mag Z:");
}

static void readAdc(SensorReadings &out) {
  out.adcLight = kAdcMax - analogRead(Pins::kAdcLight);
  out.adcTemp = analogRead(Pins::kAdcTemp);
  out.adcButtons = analogRead(Pins::kAdcButtons);
}

static void readImu(SensorReadings &out) {
  out.accelX = 0.0f;
  out.accelY = 0.0f;
  out.accelZ = 0.0f;
  out.gyroX = 0.0f;
  out.gyroY = 0.0f;
  out.gyroZ = 0.0f;
  out.magX = 0.0f;
  out.magY = 0.0f;
  out.magZ = 0.0f;

  if (!imuOnline) {
    return;
  }

  imu.readAccel();
#ifdef PRINT_CALCULATED
  out.accelX = imu.calcAccel(imu.ax);
  out.accelY = imu.calcAccel(imu.ay);
  out.accelZ = imu.calcAccel(imu.az);
#elif defined(PRINT_RAW)
  out.accelX = imu.ax;
  out.accelY = imu.ay;
  out.accelZ = imu.az;
#endif

  imu.readGyro();
#ifdef PRINT_CALCULATED
  out.gyroX = imu.calcGyro(imu.gx);
  out.gyroY = imu.calcGyro(imu.gy);
  out.gyroZ = imu.calcGyro(imu.gz);
#elif defined(PRINT_RAW)
  out.gyroX = imu.gx;
  out.gyroY = imu.gy;
  out.gyroZ = imu.gz;
#endif

  imu.readMag();
#ifdef PRINT_CALCULATED
  out.magX = imu.calcMag(imu.mx);
  out.magY = imu.calcMag(imu.my);
  out.magZ = imu.calcMag(imu.mz);
#elif defined(PRINT_RAW)
  out.magX = imu.mx;
  out.magY = imu.my;
  out.magZ = imu.mz;
#endif
}

static void readBarometer(SensorReadings &out) {
  if (!baroOnline) {
    out.baroAltitude = BaroConfig::kInvalidReading;
    out.baroTemp = BaroConfig::kInvalidReading;
    return;
  }

  out.baroAltitude = readAltitudeMeters();
  out.baroTemp = readTemperatureC();
}

static float readAltitudeMeters() {
  toggleOneShot();

  if (!waitForBaroStatus(1 << 1)) {
    return BaroConfig::kInvalidReading;
  }

  Wire.beginTransmission(BaroConfig::kAddress);
  Wire.write(BaroConfig::kRegOutPMsb);
  Wire.endTransmission(false);
  Wire.requestFrom(BaroConfig::kAddress, static_cast<uint8_t>(3));

  int counter = 0;
  while (Wire.available() < 3) {
    if (++counter > 100) {
      return BaroConfig::kInvalidReading;
    }
    delay(1);
  }

  uint8_t msb = Wire.read();
  uint8_t csb = Wire.read();
  uint8_t lsb = Wire.read();

  toggleOneShot();

  float fraction = (lsb >> 4) / 16.0f;
  return static_cast<float>((msb << 8) | csb) + fraction;
}

static float readTemperatureC() {
  toggleOneShot();

  if (!waitForBaroStatus(1 << 1)) {
    return BaroConfig::kInvalidReading;
  }

  Wire.beginTransmission(BaroConfig::kAddress);
  Wire.write(BaroConfig::kRegOutTMsb);
  Wire.endTransmission(false);
  Wire.requestFrom(BaroConfig::kAddress, static_cast<uint8_t>(2));

  int counter = 0;
  while (Wire.available() < 2) {
    if (++counter > 100) {
      return BaroConfig::kInvalidReading;
    }
    delay(1);
  }

  uint8_t msb = Wire.read();
  uint8_t lsb = Wire.read();

  float fraction = (lsb >> 4) / 16.0f;
  return static_cast<float>(msb) + fraction;
}

static bool waitForBaroStatus(uint8_t mask) {
  for (int i = 0; i < 100; ++i) {
    if (i2cRead(BaroConfig::kRegStatus) & mask) {
      return true;
    }
    delay(1);
  }
  return false;
}

static void setModeAltimeter() {
  uint8_t tempSetting = i2cRead(BaroConfig::kRegCtrl1);
  tempSetting |= (1 << 7);
  i2cWrite(BaroConfig::kRegCtrl1, tempSetting);
}

static void setOversampleRate(uint8_t sampleRate) {
  if (sampleRate > 7) {
    sampleRate = 7;
  }

  sampleRate <<= 3;
  uint8_t tempSetting = i2cRead(BaroConfig::kRegCtrl1);
  tempSetting &= 0b11000111;
  tempSetting |= sampleRate;
  i2cWrite(BaroConfig::kRegCtrl1, tempSetting);
}

static void toggleOneShot() {
  uint8_t tempSetting = i2cRead(BaroConfig::kRegCtrl1);
  tempSetting &= ~(1 << 1);
  i2cWrite(BaroConfig::kRegCtrl1, tempSetting);

  tempSetting = i2cRead(BaroConfig::kRegCtrl1);
  tempSetting |= (1 << 1);
  i2cWrite(BaroConfig::kRegCtrl1, tempSetting);
}

static void enableEventFlags() {
  i2cWrite(BaroConfig::kRegPtDataCfg, 0x07);
}

static uint8_t i2cRead(uint8_t regAddr) {
  Wire.beginTransmission(BaroConfig::kAddress);
  Wire.write(regAddr);
  Wire.endTransmission(false);
  Wire.requestFrom(BaroConfig::kAddress, static_cast<uint8_t>(1));
  return Wire.read();
}

static void i2cWrite(uint8_t regAddr, uint8_t value) {
  Wire.beginTransmission(BaroConfig::kAddress);
  Wire.write(regAddr);
  Wire.write(value);
  Wire.endTransmission(true);
}

static void updateDisplay(const SensorReadings &data) {
  ucg.setColor(1, 0, 0, 0);

  drawValueRow(data.adcTemp, 3, 0, 108, 8, 10, data.adcTemp / 8.0f, true);
  drawValueRow(data.adcLight, 3, 0, 108, 18, 20, data.adcLight / 8.0f, true);
  drawValueRow(data.adcButtons, 4, 0, 102, 28, 30, data.adcButtons / 8.0f, true);

  drawValueRow(data.baroAltitude, 4, 1, 96, 38, 40, data.baroAltitude / 8.0f, baroOnline);
  drawValueRow(data.baroTemp, 4, 1, 102, 48, 50, data.baroTemp / 8.0f, baroOnline);

  drawValueRow(data.accelX, 4, 1, 102, 58, 60, data.accelX * 100.0f, imuOnline);
  drawValueRow(data.accelY, 4, 1, 102, 68, 70, data.accelY * 100.0f, imuOnline);
  drawValueRow(data.accelZ, 4, 1, 102, 78, 80, data.accelZ * 100.0f, imuOnline);

  drawValueRow(data.gyroX, 4, 1, 90, 88, 90, data.gyroX, imuOnline);
  drawValueRow(data.gyroY, 4, 1, 90, 98, 100, data.gyroY, imuOnline);
  drawValueRow(data.gyroZ, 4, 1, 90, 108, 110, data.gyroZ, imuOnline);

  drawValueRow(data.magX, 4, 1, 90, 118, 120, data.magX, imuOnline);
  drawValueRow(data.magY, 4, 1, 90, 128, 130, data.magY, imuOnline);
  drawValueRow(data.magZ, 4, 1, 90, 138, 140, data.magZ, imuOnline);
}

static void setTextColor(bool ok) {
  if (ok) {
    ucg.setColor(0, 0, 255, 0);
  } else {
    ucg.setColor(0, 255, 0, 0);
  }
}

static uint8_t clampBarLength(float length) {
  if (length <= 0.0f) {
    return 0;
  }
  if (length >= kDisplayWidth) {
    return kDisplayWidth;
  }
  return static_cast<uint8_t>(length);
}

static void drawBar(uint8_t y, float length) {
  ucg.setColor(0, 0, 0);
  ucg.drawHLine(0, y, kDisplayWidth);
  ucg.setColor(255, 0, 255);
  ucg.drawHLine(0, y, clampBarLength(length));
}

static void drawValueRow(float value,
                         uint8_t width,
                         uint8_t precision,
                         uint8_t valueX,
                         uint8_t valueY,
                         uint8_t lineY,
                         float barLength,
                         bool okColor) {
  char buffer[12];
  dtostrf(value, width, precision, buffer);

  setTextColor(okColor);
  ucg.setPrintPos(valueX, valueY);
  ucg.print(buffer);

  drawBar(lineY, barLength);
}

static void updateStatusLeds() {
  if (digitalRead(Pins::kButtonUp) == LOW) {
    setStatusLed(true, false, false);
  } else if (digitalRead(Pins::kButtonDown) == LOW) {
    setStatusLed(false, false, true);
  } else {
    setStatusLed(false, false, false);
  }
}

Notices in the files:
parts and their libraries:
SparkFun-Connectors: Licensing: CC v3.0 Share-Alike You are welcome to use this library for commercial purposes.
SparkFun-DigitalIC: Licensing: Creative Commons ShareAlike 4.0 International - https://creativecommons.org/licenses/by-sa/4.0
